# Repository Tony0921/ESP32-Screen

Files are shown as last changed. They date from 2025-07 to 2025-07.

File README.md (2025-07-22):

# ESP32-Screen

This is a desktop project using an ESP32 and a small circular display. It features three default pages: a clock, a weather display, and a PC status monitor via AIDA64.

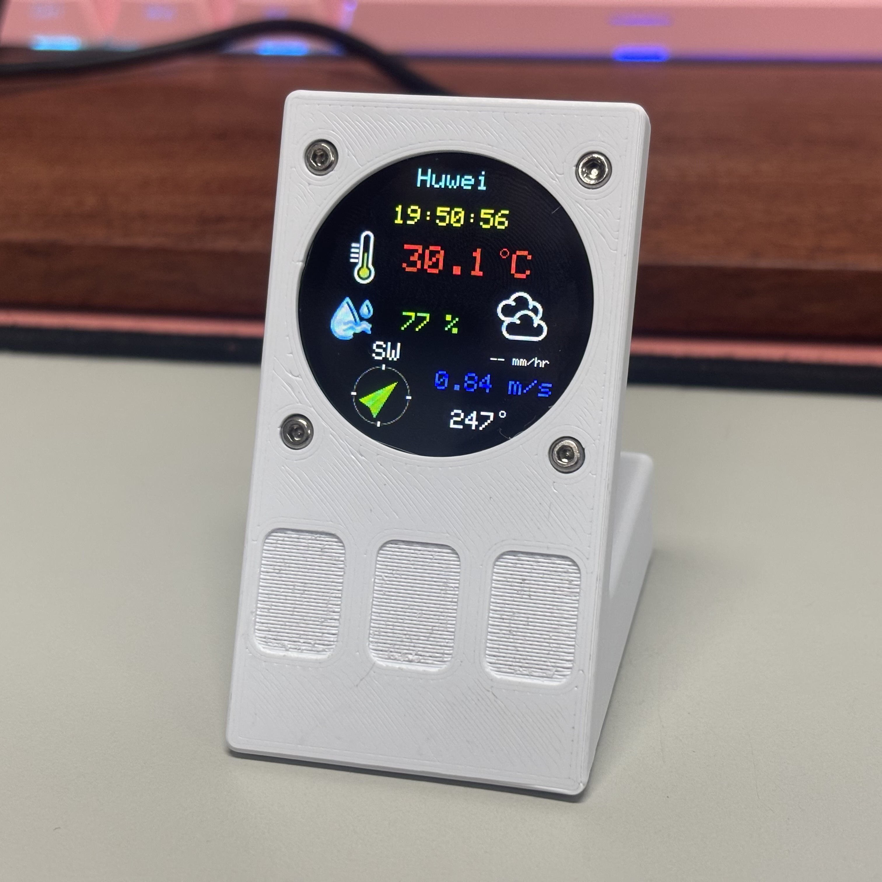
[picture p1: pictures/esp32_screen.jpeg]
esp32_screen


**Demo:**

(https://youtu.be/fua61k692V0)

---

## Hardware

* **ESP32 S3 Super Mini**
* **GC9A01 1.28" SPI LCD**
* **3 Touch Buttons**
* **8-pin Flexible Flat Cable (FFC) / Connector**
* **Custom PCB Board**
* **4 Sets of M2 Screws and Nuts**
* **3D-Printed Enclosure (Designed in SolidWorks)**

---

## EasyEDA

The hardware design files are available in the EasyEDA project:

* **Schematic Diagram**

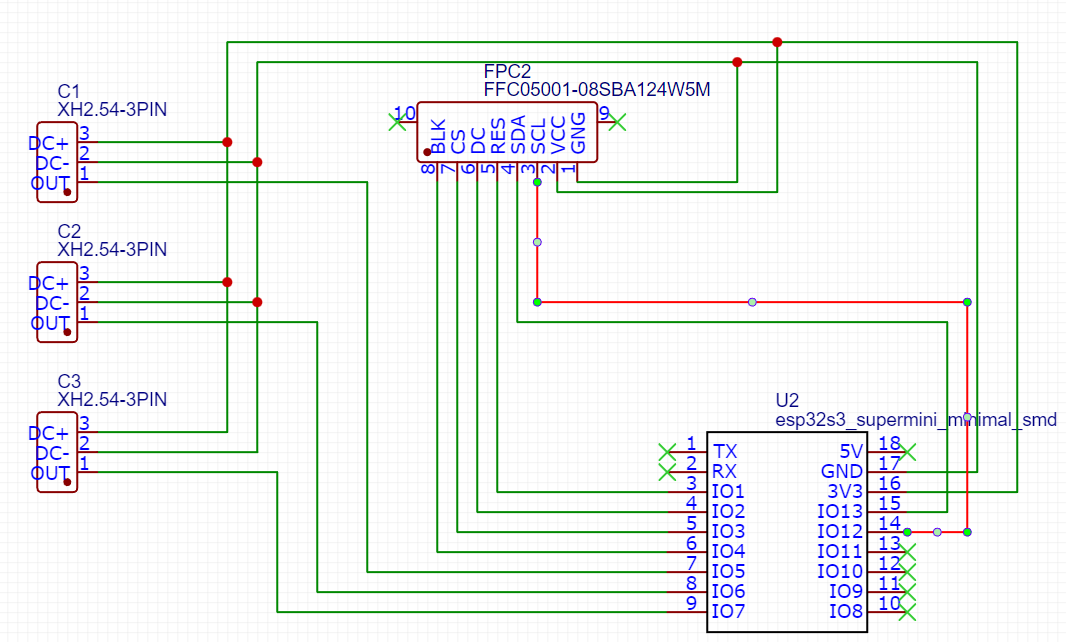
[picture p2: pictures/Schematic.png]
Schematic

<!-- ![Schematic Diagram](pictures/Schematic.png) -->

* **PCB Layout**

<!-- ![PCB Layout](/pictures/PCB_Layout.png) -->
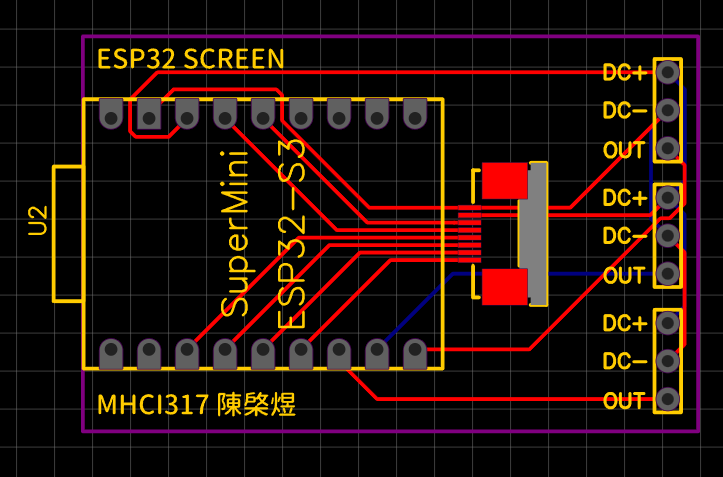
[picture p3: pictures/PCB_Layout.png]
PCB_Layout


---

## Enclosure

The enclosure is designed in SolidWorks and 3D printed. Both the SolidWorks source file and STL file are provided in the `Enclosure` [folder](Enclosure).

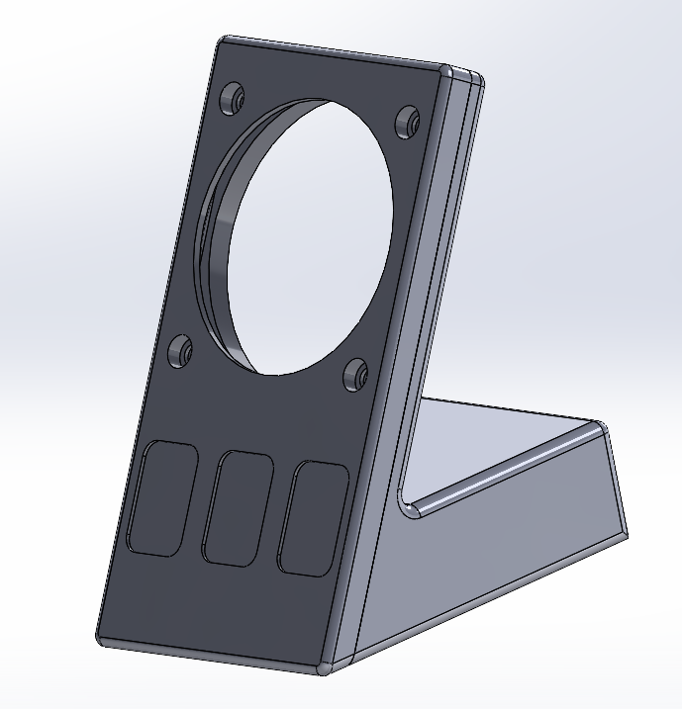
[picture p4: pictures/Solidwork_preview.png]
enclosure


---

## Arduino

### Project Structure

```
esp32_screen/
├── esp32_screen.ino (Main source code)
├── Config.h
├── Display.h
├── Display.cpp
├── Clock.h
├── Clock.cpp
├── Weather.h
├── Weather.cpp
├── Monitor.h
├── Monitor.cpp
└── data/ (Assets for LittleFS upload)
```

### Board Manager

- Install **ESP32** board support via the Board Manager.
- Recommended version: **2.0.14**

### LittleFS Setup

* Use the provided VSIX extension: `arduino-littlefs-upload-1.5.4.vsix` [file](/Arduino/arduino-littlefs-upload-1.5.4.vsix)
* For full installation and usage guide, please refer to: [Arduino IDE 2: Install ESP32 LittleFS Uploader (Upload Files to the Filesystem)](https://randomnerdtutorials.com/arduino-ide-2-install-esp32-littlefs/)

### TFT SPI Setup

* A custom `User_Setup.h` [file](Arduino/User_Setup.h) is provided.
* Replace the original file in the `TFT_eSPI` library folder (typically located at `Documents/Arduino/libraries/TFT_eSPI/`).

| SPI pins  | GPIO  |
| ---  | ----  |
| TFT_MOSI  | 13 |
| TFT_SCLK  | 12 |
| TFT_CS | 3 |
| TFT_DC | 2 |
| TFT_RST | 1 |
| TFT_BL | 4 |

### WiFi Setup

Update your WiFi credentials and AIDA64 host IP:

```
const char* ssid = "your_wifi_ssid";
const char* password = "your_wifi_password";
const char* host = "your_AIDA64_PC_ip";
```

### Time Zone Setup

Time is synchronized via NTP:

```
NTPClient timeClient(ntpUDP, "pool.ntp.org", 28800, 60000); // UTC+8 (Taiwan timezone), updates every 60 seconds
```

### OpenWeather API Key

Add your API key from OpenWeather:

```
const char* apiKey = "your_openweather_api_key";
```

### City Setup

Specify your location for weather data:

```cpp
const char* city = "Taipei,TW";
```

---

## AIDA64

Install the provided `rslcd` configuration file on your PC to enable PC monitoring over WiFi.

---

## License

This project is released under the [MIT License](LICENSE). Feel free to use and modify it.

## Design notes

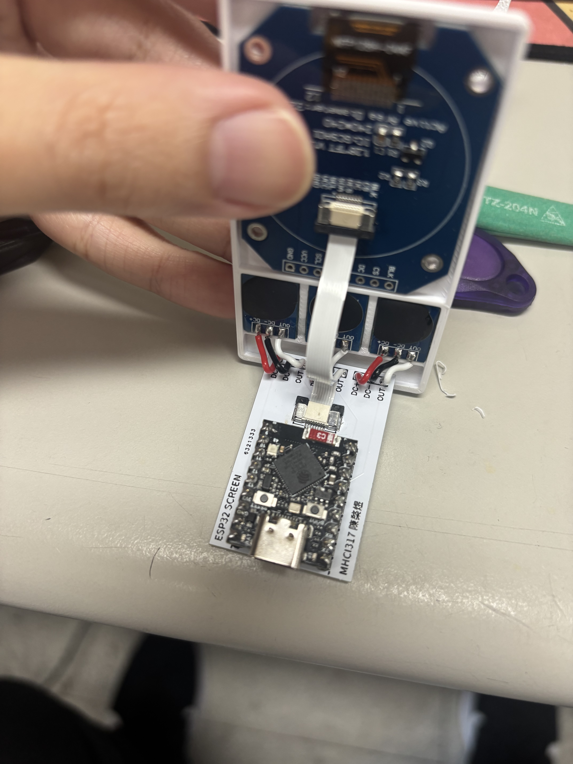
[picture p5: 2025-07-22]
pictures/esp32_screen_inner_1.jpeg

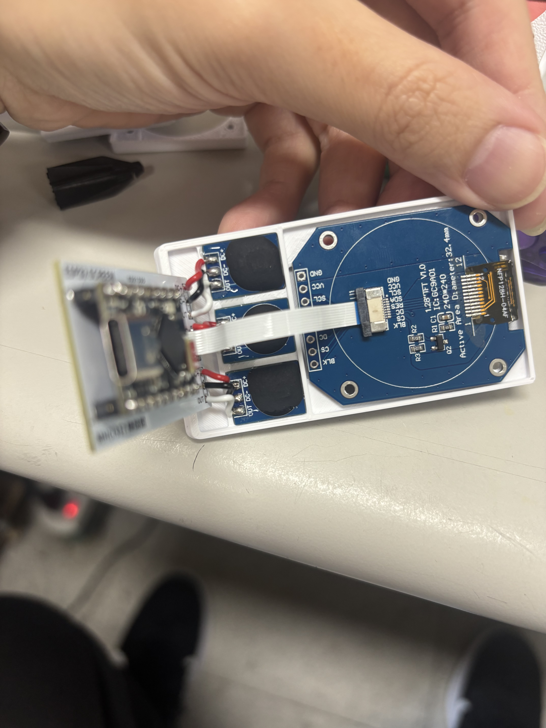
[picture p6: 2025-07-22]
pictures/esp32_screen_inner_2.jpeg

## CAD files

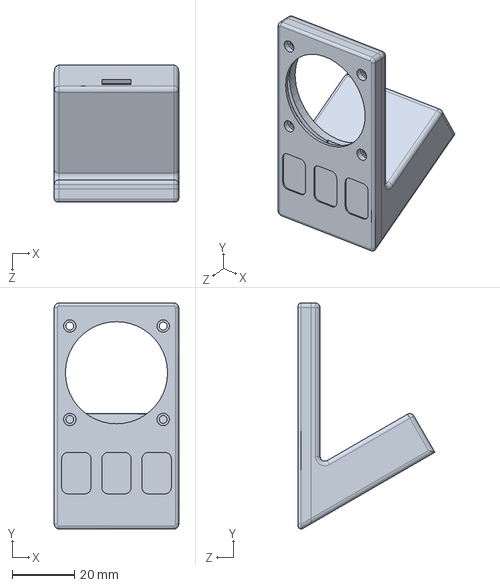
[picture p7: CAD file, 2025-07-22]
Enclosure/Solidworks/esp32_screen.SLDPRT
40.0 x 72.6 x 43.9 mm

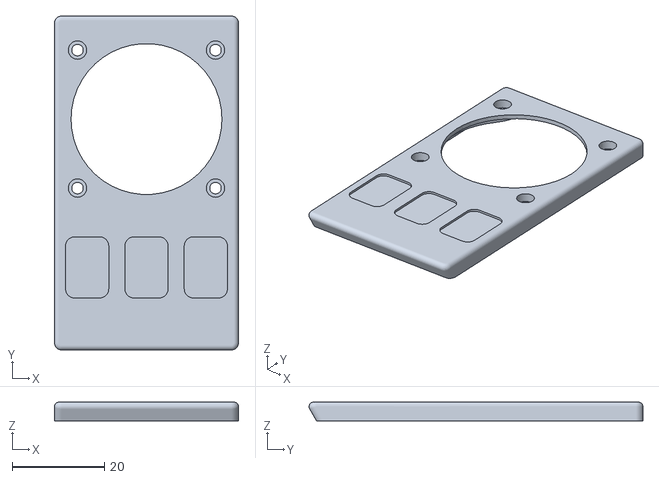
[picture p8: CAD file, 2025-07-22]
Enclosure/STL/esp32_screen_1.STL
40.0 x 72.6 x 4.10

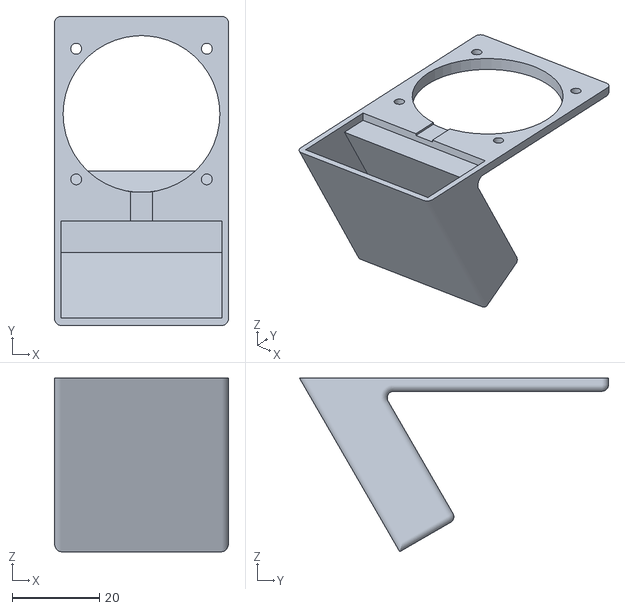
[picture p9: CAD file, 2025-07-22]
Enclosure/STL/esp32_screen_2.STL
40.0 x 71.0 x 39.8

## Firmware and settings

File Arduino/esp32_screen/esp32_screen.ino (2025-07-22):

#include "Config.h"
#include "Display.h"
#include "Weather.h"
#include "Clock.h"
#include "Monitor.h"

#define BTN_A 7
#define BTN_B 6
#define BTN_C 5

#define NUM_LEDS 1
#define DATA_PIN 48
#define LED_TYPE WS2812
#define BRIGHTNESS 64
#define COLOR_ORDER GRB

// TFT 物件
TFT_eSPI tft = TFT_eSPI();

// WiFi 憑證
const char* ssid = "";
const char* password = "";
const char *host = "";

// NTP 設置
WiFiUDP ntpUDP;
NTPClient timeClient(ntpUDP, "pool.ntp.org", 28800, 60000); // UTC+8 (台灣時區)，每60秒更新

// OpenWeatherMap API 設定
const char* apiKey = "";
const char* city = "Taipei,TW";

CRGB leds[NUM_LEDS];

bool haveNewData = false;
bool needUpdateWeather = false;
bool needUpdateDisplay = false;

WiFiClient client;
bool isHostConnect = false;

// 輪播控制
int currentDisplay = 0;  // 當前顯示的數據索引（0-4）
unsigned long lastSwitchTime = 0;
const unsigned long switchInterval = 3000;  // 切換間隔（3秒）
bool needSwitchDisplay = false;

// 計時相關變數
unsigned long previousMillis = 0; // 上次執行時間
const long interval = 1000;      // 間隔時間（毫秒，1秒）
int counter = 0;                 // 計數器

int show_status = 0;

volatile unsigned long lastInterruptTimeA = 0; // 上次中斷時間
volatile unsigned long lastInterruptTimeB = 0; // 上次中斷時間
volatile unsigned long lastInterruptTimeC = 0; // 上次中斷時間
const unsigned long debounceDelay = 500; // 防彈跳延遲 (毫秒)

void setup() {
  // 初始化序列埠
  Serial.begin(115200);

  pinMode(BTN_A, INPUT_PULLDOWN);
  pinMode(BTN_B, INPUT_PULLDOWN);
  pinMode(BTN_C, INPUT_PULLDOWN);

  // 初始化 LittleFS
  if (!LittleFS.begin()) {
    Serial.println("LittleFS 初始化失敗");
    return;
  }
  Serial.println("LittleFS 初始化成功");

  // 初始化 TFT
  tft.begin();
  tft.setRotation(2); // 調整顯示方向
  tft.fillScreen(TFT_BLACK);

  initScreen();


  // 連接到 WiFi
  WiFi.begin(ssid, password);
  while (WiFi.status() != WL_CONNECTED) {
    delay(500);
    Serial.print(".");
  }
  Serial.println("\nWiFi 已連接");
  Serial.println("");
  Serial.println("IP address: ");
  Serial.println(WiFi.localIP());


  // 初始化 NTP
  timeClient.begin();
  
  attachInterrupt(digitalPinToInterrupt(BTN_A), btnHandlerA, RISING);
  attachInterrupt(digitalPinToInterrupt(BTN_B), btnHandlerB, RISING);
  attachInterrupt(digitalPinToInterrupt(BTN_C), btnHandlerC, RISING);

  FastLED.addLeds<LED_TYPE, DATA_PIN, COLOR_ORDER>(leds, NUM_LEDS);
  FastLED.setBrightness(BRIGHTNESS);

  getWeather();

  connectHost();

  tft.fillScreen(TFT_BLACK); //clear screen

}

void loop() {

  // 獲取當前時間
  unsigned long currentMillis = millis();

  // 檢查是否達到 1 秒間隔
  if (currentMillis - previousMillis >= interval) {
    timeClient.update();
    if(show_status==0){
      leds[0] = CRGB::Green;
      updateClockScreen();
    }else if(show_status==1){
      leds[0] = CRGB::Red;
      updateWeatherScreen();
    }else if(show_status==2){
      leds[0] = CRGB::Blue;
      updateMonitorScreen();
      
    }
    FastLED.show();

    // 更新上次執行時間
    previousMillis = currentMillis;
  }
}

void initScreen(){
  // 顯示標題
  tft.fillScreen(TFT_BLACK); //clear screen
  tft.setTextColor(TFT_WHITE, TFT_BLACK);
  tft.setTextDatum(MC_DATUM);
  tft.setFreeFont(&FreeSansBold12pt7b);  // 使用免費字型
  tft.setTextColor(rgb24to16("FFFFFF"), TFT_BLACK);
  tft.drawString("ESP32 Screen", 120, 120);
  delay(3000);
  
  // 顯示連接WiFi
  tft.fillScreen(TFT_BLACK); //clear screen
  drawIcon("/wifi.bmp", 120-25, 80-25);
  tft.setTextDatum(MC_DATUM);
  tft.setFreeFont(&FreeMonoBold12pt7b);  // 使用免費字型
  tft.setTextColor(rgb24to16("615AFF"), TFT_BLACK);
  tft.drawString("Wi-Fi", 120, 120);
  tft.setTextColor(TFT_WHITE, TFT_BLACK);
  tft.drawString("Connecting...", 120, 150);
}

void btnHandlerA(){
  unsigned long currentTime = millis();
  if (currentTime - lastInterruptTimeA > debounceDelay) {
    Serial.println("btn a");
    show_status++;
    if(show_status > 2){
      show_status=0;
    }
    if(show_status==1){
      needUpdateDisplay = true;
    }
    lastInterruptTimeA = currentTime; // 更新上次中斷時間
  }
}
void btnHandlerB(){
  unsigned long currentTime = millis();
  if (currentTime - lastInterruptTimeB > debounceDelay) {
    Serial.println("btn b");
    if(show_status==1){
      needUpdateWeather = true;
    }
    if(show_status==2){
      needSwitchDisplay = true;
    }
    lastInterruptTimeB = currentTime; // 更新上次中斷時間
  }
}
void btnHandlerC(){
  unsigned long currentTime = millis();
  if (currentTime - lastInterruptTimeC > debounceDelay) {
    Serial.println("btn c");
    show_status--;
    if(show_status < 0){
      show_status=2;
    }
    if(show_status==1){
      needUpdateDisplay = true;
    }
    lastInterruptTimeC = currentTime; // 更新上次中斷時間
  }
}

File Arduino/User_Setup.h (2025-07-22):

//                            USER DEFINED SETTINGS
//   Set driver type, fonts to be loaded, pins used and SPI control method etc.
//
//   See the User_Setup_Select.h file if you wish to be able to define multiple
//   setups and then easily select which setup file is used by the compiler.
//
//   If this file is edited correctly then all the library example sketches should
//   run without the need to make any more changes for a particular hardware setup!
//   Note that some sketches are designed for a particular TFT pixel width/height

// User defined information reported by "Read_User_Setup" test & diagnostics example
#define USER_SETUP_INFO "User_Setup"

// Define to disable all #warnings in library (can be put in User_Setup_Select.h)
//#define DISABLE_ALL_LIBRARY_WARNINGS

// ##################################################################################
//
// Section 1. Call up the right driver file and any options for it
//
// ##################################################################################

// Define STM32 to invoke optimised processor support (only for STM32)
//#define STM32

// Defining the STM32 board allows the library to optimise the performance
// for UNO compatible "MCUfriend" style shields
//#define NUCLEO_64_TFT
//#define NUCLEO_144_TFT

// STM32 8-bit parallel only:
// If STN32 Port A or B pins 0-7 are used for 8-bit parallel data bus bits 0-7
// then this will improve rendering performance by a factor of ~8x
//#define STM_PORTA_DATA_BUS
//#define STM_PORTB_DATA_BUS

// Tell the library to use parallel mode (otherwise SPI is assumed)
//#define TFT_PARALLEL_8_BIT
//#defined TFT_PARALLEL_16_BIT // **** 16-bit parallel ONLY for RP2040 processor ****

// Display type -  only define if RPi display
//#define RPI_DISPLAY_TYPE // 20MHz maximum SPI

// Only define one driver, the other ones must be commented out
// #define ILI9341_DRIVER       // Generic driver for common displays
//#define ILI9341_2_DRIVER     // Alternative ILI9341 driver, see https://github.com/Bodmer/TFT_eSPI/issues/1172
//#define ST7735_DRIVER      // Define additional parameters below for this display
//#define ILI9163_DRIVER     // Define additional parameters below for this display
//#define S6D02A1_DRIVER
//#define RPI_ILI9486_DRIVER // 20MHz maximum SPI
//#define HX8357D_DRIVER
//#define ILI9481_DRIVER
//#define ILI9486_DRIVER
//#define ILI9488_DRIVER     // WARNING: Do not connect ILI9488 display SDO to MISO if other devices share the SPI bus (TFT SDO does NOT tristate when CS is high)
//#define ST7789_DRIVER      // Full configuration option, define additional parameters below for this display
//#define ST7789_2_DRIVER    // Minimal configuration option, define additional parameters below for this display
//#define R61581_DRIVER
//#define RM68140_DRIVER
//#define ST7796_DRIVER
//#define SSD1351_DRIVER
//#define SSD1963_480_DRIVER
//#define SSD1963_800_DRIVER
//#define SSD1963_800ALT_DRIVER
//#define ILI9225_DRIVER
#define GC9A01_DRIVER

// Some displays support SPI reads via the MISO pin, other displays have a single
// bi-directional SDA pin and the library will try to read this via the MOSI line.
// To use the SDA line for reading data from the TFT uncomment the following line:

// #define TFT_SDA_READ      // This option is for ESP32 ONLY, tested with ST7789 and GC9A01 display only

// For ST7735, ST7789 and ILI9341 ONLY, define the colour order IF the blue and red are swapped on your display
// Try ONE option at a time to find the correct colour order for your display

//  #define TFT_RGB_ORDER TFT_RGB  // Colour order Red-Green-Blue
//  #define TFT_RGB_ORDER TFT_BGR  // Colour order Blue-Green-Red

// For M5Stack ESP32 module with integrated ILI9341 display ONLY, remove // in line below

// #define M5STACK

// For ST7789, ST7735, ILI9163 and GC9A01 ONLY, define the pixel width and height in portrait orientation
// #define TFT_WIDTH  80
// #define TFT_WIDTH  128
// #define TFT_WIDTH  172 // ST7789 172 x 320
// #define TFT_WIDTH  170 // ST7789 170 x 320
#define TFT_WIDTH  240 // ST7789 240 x 240 and 240 x 320
// #define TFT_HEIGHT 160
// #define TFT_HEIGHT 128
// #define TFT_HEIGHT 240 // ST7789 240 x 240
// #define TFT_HEIGHT 320 // ST7789 240 x 320
#define TFT_HEIGHT 240 // GC9A01 240 x 240

// For ST7735 ONLY, define the type of display, originally this was based on the
// colour of the tab on the screen protector film but this is not always true, so try
// out the different options below if the screen does not display graphics correctly,
// e.g. colours wrong, mirror images, or stray pixels at the edges.
// Comment out ALL BUT ONE of these options for a ST7735 display driver, save this
// this User_Setup file, then rebuild and upload the sketch to the board again:

// #define ST7735_INITB
// #define ST7735_GREENTAB
// #define ST7735_GREENTAB2
// #define ST7735_GREENTAB3
// #define ST7735_GREENTAB128    // For 128 x 128 display
// #define ST7735_GREENTAB160x80 // For 160 x 80 display (BGR, inverted, 26 offset)
// #define ST7735_ROBOTLCD       // For some RobotLCD Arduino shields (128x160, BGR, https://docs.arduino.cc/retired/getting-started-guides/TFT)
// #define ST7735_REDTAB
// #define ST7735_BLACKTAB
// #define ST7735_REDTAB160x80   // For 160 x 80 display with 24 pixel offset

// If colours are inverted (white shows as black) then uncomment one of the next
// 2 lines try both options, one of the options should correct the inversion.

// #define TFT_INVERSION_ON
// #define TFT_INVERSION_OFF


// ##################################################################################
//
// Section 2. Define the pins that are used to interface with the display here
//
// ##################################################################################

// If a backlight control signal is available then define the TFT_BL pin in Section 2
// below. The backlight will be turned ON when tft.begin() is called, but the library
// needs to know if the LEDs are ON with the pin HIGH or LOW. If the LEDs are to be
// driven with a PWM signal or turned OFF/ON then this must be handled by the user
// sketch. e.g. with digitalWrite(TFT_BL, LOW);

// #define TFT_BL   32            // LED back-light control pin
// #define TFT_BACKLIGHT_ON HIGH  // Level to turn ON back-light (HIGH or LOW)
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
